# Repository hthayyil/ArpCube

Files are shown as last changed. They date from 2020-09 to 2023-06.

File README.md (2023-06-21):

# ArpCube
**Arduino Code and schematics for the ArpCube Midi Controller created by Sister Engineering**

The ArpCube is an Arduino powered MIDI controller. The cube can be plugged into a computer to process the button controls into MIDI, 
or it can be plugged into any device that understands MIDI. 
The ArpCube can act as a standalone MIDI trigger or it can be used as an arpeggiator. 
When in arpeggiator mode, the ArpCube allows a user to step through a selected sequence of notes based on the input buttons. 

Powered by USB C. MIDI signals are sent using a DIN socket. 
## Modes

**MIDI Mode**
When in MIDI mode, pressing a button will send it’s corresponding MIDI On signal out once, and releasing a button will send a MIDI Off signal. 
Pressing and holding a button will sustain the note until the button is released. 
When in MIDI Mode the user can use the KEY potentiometer to choose which key the notes are mapped to. 
The chosen key will be displayed on the LCD screen.
The user can also use the OCTAVE potentiometer to transpose the notes on each key up or down octaves.

**Mono Arp Mode** 
In Mono mode the cube steps through a sequence of 32 steps. 
Each step is represented by a button, and when a step is reached the button light will turn on. 
When the arpeggiator reaches a step and the user presses any of the 32 buttons, that step will save the note that was just pressed and replay that note when it reaches that step. 
Every step can only support one note, so if a step already has a note saved and the user presses another note, the previously programmed note will be erased and the new note will be saved. 
The user can transpose octave and keys using the OCTAVE and KEY Potentiometer, and the user can also control the BPM using the BPM Potentiometer.
The BPM, and key will be displayed on the LCD screen.

**Poly Arp Mode** 
In Poly Mode the cube steps through a sequence of 8 steps. 
Each step is represented by a column on the button matrix. Each step can hold up to 4 notes. 
When the sequence is on a step and a user presses a key that note will be added to that step. 
When the step has reached 4 notes stored, and the user adds another note, all old notes will be cleared and the new note will be stored. 
The user can transpose octave and keys using the OCTAVE and KEY pot, and control BPM using the BPM pot.
The BPM, and key will be displayed on the LCD screen.

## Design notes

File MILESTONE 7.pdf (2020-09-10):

# ArpCube

An Arduino MIDI controller by: Hanna Thayyil
Hthayyi2
Hthayyi2@uic.edu
Wisam Abunimeh
Wabuni2
Wabuni2@uic.edu

Abstract:

The ArpCube is an Arduino powered MIDI controller. The cube can be plugged into a computer to process the button controls into MIDI, or it can be plugged into a device that understands MIDI such as a synthesizer. The ArpCube can act as a standalone MID trigger or it can be used as an arpeggiator. An arpeggio is a musical term for playing the notes of a chord in succession. When in arpeggiator mode, the ArpCube allows a user to step through a selected sequence of notes based on the input buttons. The ArpCube does not support MIDI-IN or MIDI-THRU signals, only MIDI-OUT.
Description & How to Use:
The ArpCube is inspired by the Novation Launchpad, and the Monome MIDI controller. It can be used with any music software or it can be used with other hardware synthesizers that understand MIDI. The ArpCube is not a standalone instrument, it does not create any audio, it must be used in tandem with a Midi receiving instrument or computer digital audio workspace.
The ArpCube features 32 back-lit buttons used as inputs and outputs. Each button sends a MIDI signal that represents a note. The cube has 3 different modes -MIDI mode- When in MIDI mode pressing a button will send it’s corresponding MIDI On signal out once, and releasing a button will send a MIDI Off signal. Pressing and holding a button will sustain the note until the button is released. When in MIDI Mode the user can use the KEY potentiometer to choose which key the notes are mapped to. The user can also use the OCTAVE potentiometer to transpose the notes on each key up or down octaves.

-Mono Arp Mode- In Mono mode the cube steps through a sequence of 32 steps. Each step is represented by the button, and when a step is reached the button light will turn on. When the arpeggiator reaches a step and the user presses any of the 32 buttons, that step will save the note that was just pressed and play that note when it reaches that step. Every step can only support one note, so if a step already has a note saved and the user presses another note, the old note will be erased and the new note will be saved. The user can transpose octave and keys using the OCTAVE and KEY Potentiometer, and the user can also control the BPM using the BPM Potentiometer.
-Poly Arp Mode- In Poly Mode the cube steps through a sequence of 8 steps. Each step is represented by a column on the button matrix. Each step can hold up to 4 notes. When the sequence is on a step and a user presses a key that note will be added to that step. When the step has reached 4 notes stored, and the user adds another note, all old notes will be cleared and the new note will be stored. The user can transpose octave and keys using the OCTAVE and KEY pot, and control BPM using the BPM pot.
The ArpCube was designed to make use of two Arduino’s based on the sheer amount of inputs used. They will be connected using Bluetooth bus. One Arduino will receive information from the various inputs and another will be used to send outputs to both the ArpCube and other connected devices. The ArpCube will use a DIN socket to send MIDI messages to a MIDI understanding device.
INPUT/OUTPUT
Inputs for the device will be 32 buttons, three potentiometers and two switches. The potentiometers allow transposing key, octave and changing BPM. The two switches let you toggle between the three modes. Output will be 32 3mm LED’s used as indicators that a button is switched on or off- these LED’s back light the buttons. We will be using Adafruit’s Trellis keypad driver for simplicity. An LCD screen is used as output to display which mode the user is in, as well as which key they are in and what their current BPM is.

## Original Work

The ArpCube is unique because it acts as both a standalone MIDI controller and an arpeggiator. Many documented projects only feature a controller, but the arpeggiator algorithms are completely original. Many DIY projects also only feature 16 or 8 buttons. Since there are 7 notes or 12 semitones in a western scale, we wanted to make the number of buttons on the ArpCube be able to support at least 2 octaves. The Arpcube however supports every possible MIDI octave. We have also not encountered MIDI controller that allows the user to traverse through different Keys, since it is not immediately clear which button is programmed to which note, we wanted to make the MIDI controller easily intuitive and musical. We wrote two original libraries, for Arpeggiating and Note Mapping.
Materials:
2x Arduino Uno
2x Silicone Elastomer Key Pads - https://www.adafruit.com/product/1611 2x Adafruit Trellis PCB Drivers https://www.adafruit.com/product/1616 32x While 3mm LED
1x LCD screen
2x resistors (220 Ohm)
3x Rotary potentiometer (50K) 1x Capacitor (0.05 mF)
2x Toggle Switch
1x DIN socket
References

Sending and Receiving MIDI (we will be using MIDI Send not receive) https://www.instructables.com/id/Send-and-Receive-MIDI-with-Arduino/

Serial to MIDI References
https://projectgus.github.io/hairless-midiserial/

Arduino sequencer used as reference https://learn.sparkfun.com/tutorials/build-an-auduino-step-sequencer/all

Libraries Used: Software Serial, Arduino STL, LiquidCrystal, Wire.h, Adafruit Trellis, MIDIUSB, MIDI.h

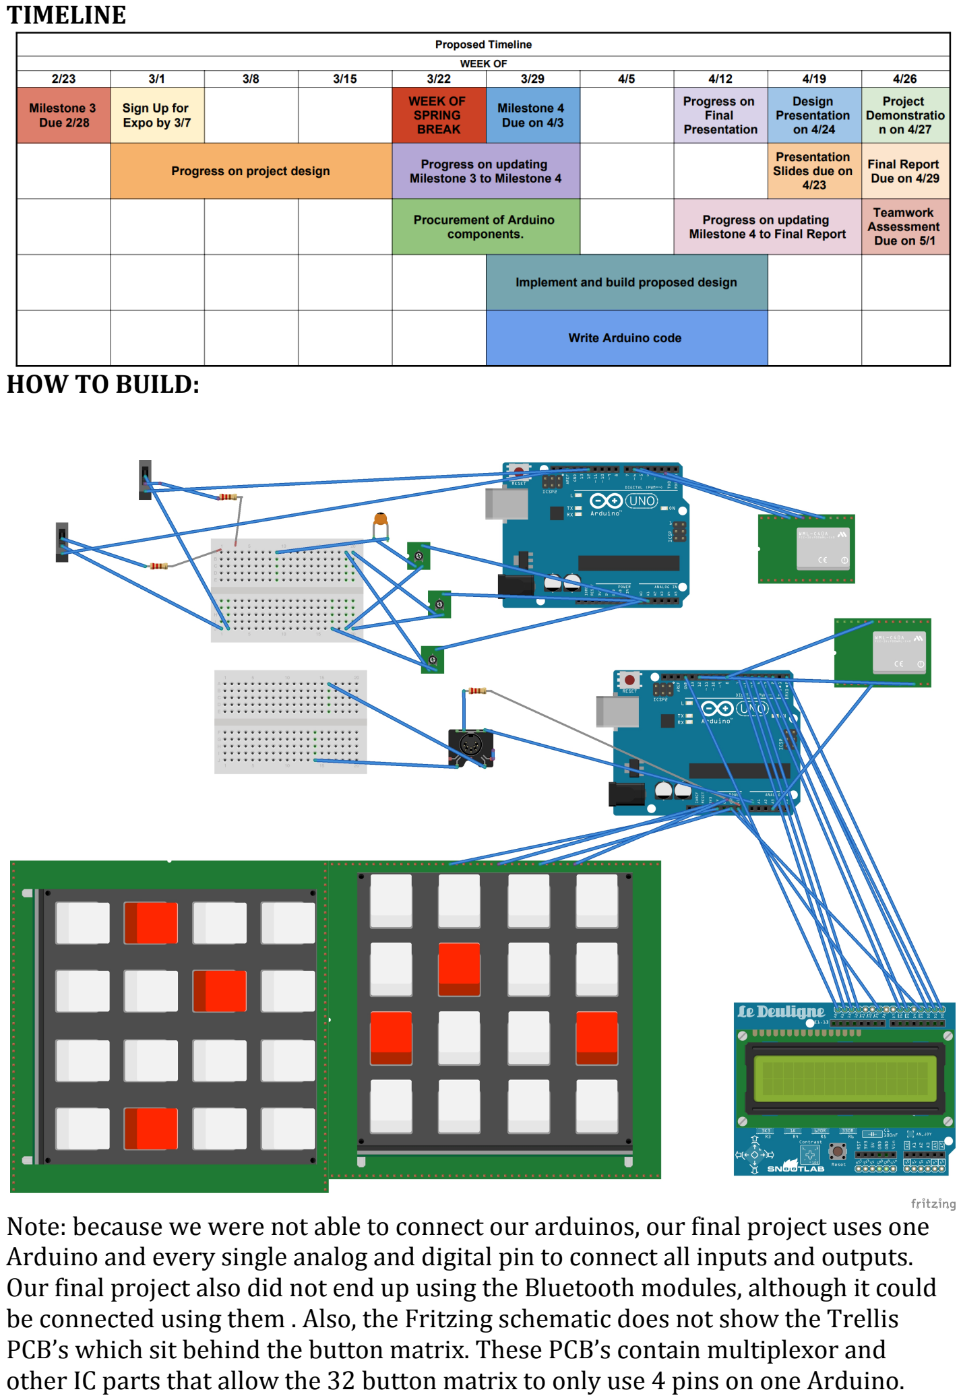
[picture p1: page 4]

TIMELINE

HOW TO BUILD:

Note: because we were not able to connect our arduinos, our final project uses one Arduino and every single analog and digital pin to connect all inputs and outputs. Our final project also did not end up using the Bluetooth modules, although it could be connected using them . Also, the Fritzing schematic does not show the Trellis PCB’s which sit behind the button matrix. These PCB’s contain multiplexor and other IC parts that allow the 32 button matrix to only use 4 pins on one Arduino.

Connect Trellis Vin to 5V and Ground to ground. Connect the INT wire to pin #A2
Connect I2C SDA pin to your Arduino SDA line PIN A4 Connect I2C SCL pin to your Arduino SCL line PIN A5 All Trellises share the SDA, SCL and INT pin.
OCTAVE POT - potPin is on analog pin 0
TEMPO POT is on analog pin 1
SWITCH1 is on digital Pin 6
SWITCH 2 is on digital Pin 7
KEY POT is on pin A2

LCD set up: LiquidCrystal lcd(13, 12, 8, 9, 10, 11);

-Commented in the code sketch are the above instructions on which inputs must be connected to which pins.

Challenges:
Debouncing potentiometers during the arpeggiator was a challenge which was solved using a 0.05 mF capacitor.
Testing the DIN socket with devices other then a digital audio workstation was a challenge because of quarantine restrictions. Currently, if the user connects a MIDI out cable to USB to the computer, it works perfectly fine, but this was not tested connecting to any other device.

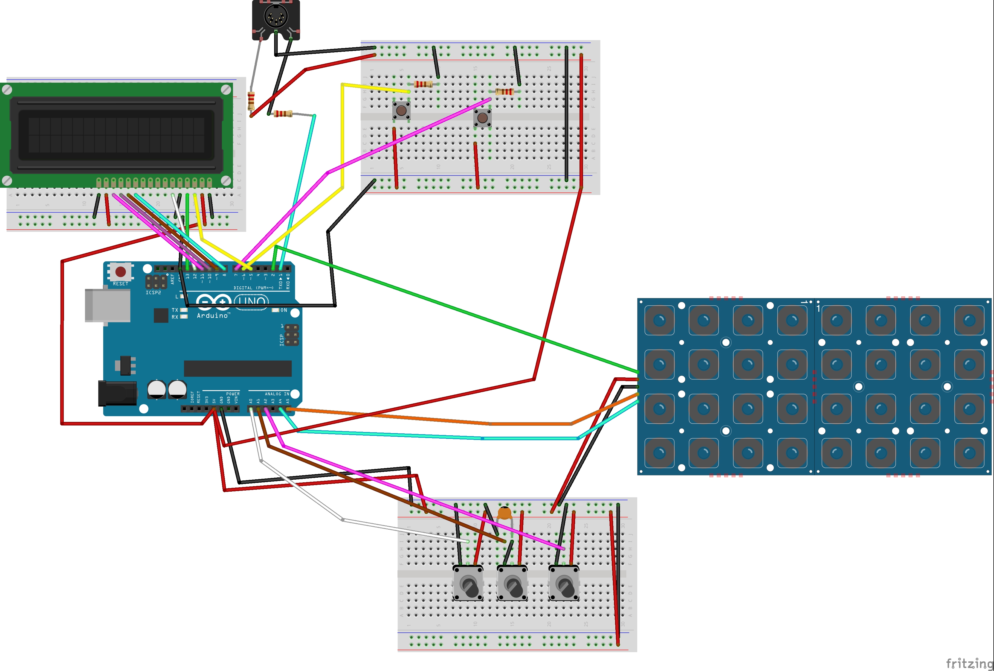
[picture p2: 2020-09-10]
arpcube-final.jpg

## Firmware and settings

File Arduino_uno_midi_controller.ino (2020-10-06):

/*Arduino Code for the ARP CUBE 
 * written by Hanna Thayyil 
 * https://github.com/hthayyil/ArpCube
*/

#include <SoftwareSerial.h>
#include <MIDImap.h>
#include <ArduinoSTL.h>
#include <LiquidCrystal.h> 
#include <Wire.h>
#include "Adafruit_Trellis.h"
#include <MIDI.h>
#include <ARPbeta.h>




//DEFINE MODES:
#define MIDICONTROLLER 0
#define ARPCUBE 1
#define POLY 2
#define FUNCTION 3


// Define MODE: MIDICONTROLLER MODE is set as default
int MODE = MIDICONTROLLER; 

//Call upon Trellis libary for button pad commands
Adafruit_Trellis matrix0 = Adafruit_Trellis();
Adafruit_Trellis matrix1 = Adafruit_Trellis();

//Inititalize TRELLIS
Adafruit_TrellisSet trellis =  Adafruit_TrellisSet(&matrix0, &matrix1);

//set the interrupt pin to A2
#define INTPIN 2
//set the number of trellis boards and number of keys we are using
#define NUMTRELLIS 2
#define numKeys (NUMTRELLIS * 16)

/*
 Connect Trellis Vin to 5V and Ground to ground.
 Connect the INT wire to pin #A2
 Connect I2C SDA pin to your Arduino SDA line PIN A4
 Connect I2C SCL pin to your Arduino SCL line PIN A5
 All Trellises share the SDA, SCL and INT pin
 OCTAVE POT - potPin is on analog pin 0
 TEMPO POT is on analog pin 1
 SWITCH is on digital Pin 6
 SWITCH 2 is on digital pin7
 KEY POT is on pin A2
*/

//DIN 2 to GROUND
//DIN 4 to 220 OHM resistor to D1
//DIN 5 to 5V
 

//SET MIDI COMMANDS
int velocity = 100;//velocity of MIDI notes, must be between 0 and 127
 //higher velocity usually makes MIDI instruments louder
int noteON = 144;//144 = 10010000 in binary, note on command
int noteOFF = 128;//128 = 10000000 in binary, note off command

//OCTAVE POT is on analog pin 0
int potPin = 0; //potentiometer is on A0
long potVal; //value to store potentiometer reading
long prevPotVal = 0;

//TEMPO POT is on analog pin 1
int tempoPin = 1;
long tempo; //value to store potentiometer reading
long prevTempo = 0;
long BPM;

//SWITCH is on digital pin 6
int switchPin = 6;

//BUTTON is on pin 7
int button = 7;
//unsigned long lastDebounceTime = 0;  // the last time the output pin was toggled
//unsigned long debounceDelay = 50;    // the debounce time; increase if the output flickers
//int prevButtonState = LOW;

//function button is on pin 3
int funcButton = 3;
int led = 4; 

//POTENTIOMETER to indicate key is on pin A2
int keyPot = 2;
long keyVal;

volatile int arpSeq[32];
//bool wasPressed = false;
//volatile int polySeq[8][4];

//used for poly mode
int noteOrderPoly[8][4] = 
{ {28, 29, 30, 31},
  {24, 25, 26, 27},
  {20, 21, 22, 23},
  {16, 17, 18, 19},
  {12, 13, 14, 15},
  {8,   9, 10, 11},
  {4,   5,  6,  7},
  {0,   1,  2,  3} };

//Maps trellis matrix button order
int noteOrder[32] = {
  28, 24, 20, 16, 12 ,8, 4 ,0, 
  29, 25, 21, 17, 13, 9, 5,1,
  30, 26, 22, 18, 14, 10, 6, 2,
  31, 27, 23, 19, 15, 11, 7, 3
};


int numSteps = 31;

//Class objects- defined in the MIDImap and ARP libraries
MIDImap mp;
ARP arp;

//Set Contrast: used to surpass need for POT on LCD
int Contrast=100;
LiquidCrystal lcd(13, 12, 8, 9, 10, 11);  

//INITIALIZE SOFTWARE SERIAL: to use DIN Socket
const byte rxPin = 0; // not used for the moment
const byte txPin = 1;
SoftwareSerial mySerial(rxPin, txPin);
boolean changed = false;

//ClearSequence: Resets the ARP sequence
void clearSequence(){
   for(int i=0; i<32; i++){
      arpSeq[i] = -1;
   }
   numSteps = 31;
}

//function to clear all LEDS
void clearLEDS(){
      for (uint8_t i=0; i<numKeys; i++) {
           // MIDImessage(noteOFF, mp.noteCalc(i, analogRead(potPin),analogRead(keyPot)), velocity);//turn note off 
            trellis.clrLED(i);
        }     
      trellis.writeDisplay();    
}

//function to clear all notes turn everything off
void clearNotes(){
 for (uint8_t i=0; i<127; i++) {
   MIDImessage(noteOFF, i, velocity);//turn note off 
}
  
}

  //send MIDI message through USB port
void MIDImessage(int command, int MIDInote, int MIDIvelocity) {
  Serial.write(command);//send note on or note off command 
  Serial.write(MIDInote);//send pitch data
  Serial.write(MIDIvelocity);//send velocity data
}

void setup() {
   // Set MIDI baud rate:
   //9600 to interface with Hairless midi software 
   pinMode(button, INPUT);
   
   pinMode( txPin, OUTPUT);
   pinMode(funcButton, INPUT);
   pinMode(led, OUTPUT);
   
   //initialize contrast for LCD
   analogWrite(5,Contrast);
   
   lcd.begin(16, 2);
   lcd.print("ARPCUBE");
   
   Serial.begin(31250);
 // Serial.begin(9600);
   clearSequence();
  // INT pin requires a pullup
  pinMode(INTPIN, INPUT);

  pinMode(switchPin, INPUT);
 keyVal = analogRead(keyPot);

//set default tempo to 120 BPM 60k/120
 tempo = 500; 
 
  
 // attachInterrupt(digitalPinToInterrupt(INTPIN), addButton, FALLING);
  
  // begin() with the addresses of each panel in order
  trellis.begin(0x71, 0x70);  // only one

  // light up all the LEDs in order
  for (uint8_t i=0; i<numKeys; i++) {
    trellis.setLED(i);
    trellis.writeDisplay();
    if (i == 2 || i == 4 || i == 5 || i == 7) {
      delay(100);//hold note for 300ms
     } else if (i == 8) {
        delay(100);//hold note for 300ms
      } else if (i == 13 || i == 15) {      
        delay(100);//hold note for 300ms
      }
  }
  
  // then turn them all off
  for (uint8_t i=0; i<numKeys; i++) {
    trellis.clrLED(i);
    trellis.writeDisplay();    
    delay(30);
  }
}//end setup


void loop() {

  //read the value of the pin to determine which mode to be in
  if (digitalRead(switchPin) == HIGH) {
    MODE = MIDICONTROLLER;
    arp.clear();
    clearSequence();
    lcd.setCursor(0,0);
    lcd.print("MIDI MODE          ");
    lcd.setCursor(0, 1); 
    keyVal = analogRead(keyPot);
    lcd.print(mp.printKey(keyVal).c_str());
  }
 
  
   else { 
     clearNotes();
      MODE = ARPCUBE;
      lcd.setCursor(0,0);
      lcd.print("MONO BPM: ");
      lcd.print(BPM);
      lcd.setCursor(0, 1); 
      keyVal = analogRead(keyPot);
      lcd.print(mp.printKey(keyVal).c_str());
   }
  
  delay(30); // 30ms delay helps for latency
  
  //octave pot
   potVal = analogRead(potPin);


  if (keyVal!= analogRead(keyPot)){
     
     lcd.setCursor(0, 1); 
     keyVal = analogRead(keyPot);
     lcd.print(mp.printKey(keyVal).c_str());
  }


 
  //MIDICONTROLLER MODE
 if  (MODE == MIDICONTROLLER) {
    
    // If a button was just pressed or released
    if (trellis.readSwitches()) {
      // go through every button and check new status
      
      for (uint8_t i=0; i<numKeys; i++) {
        if (trellis.justPressed(i)) {
          
            MIDImessage(noteON, mp.noteCalc(i, potVal, keyVal), velocity);//turn note on
            trellis.setLED(i);
        } 
         // if it was released, turn it off
         if (trellis.justReleased(i)) {
            MIDImessage(noteOFF, mp.noteCalc(i, potVal, keyVal), velocity);//turn note off 
            trellis.clrLED(i);
        }
      }
      
      // tell the trellis to set the LEDs we requested
      trellis.writeDisplay();
    }
   
  
  } //end midicontroller mode


//ARP MODE

while (MODE ==ARPCUBE) {
      lcd.setCursor(0,0);
      lcd.print("MONO BPM: ");
      lcd.print(BPM);
      lcd.setCursor(0, 1); 
      keyVal = analogRead(keyPot);
      lcd.print(mp.printKey(keyVal).c_str());
  
  for (uint8_t k=0; k<=numSteps; k++) {
  
  //read Mode switch 
    if (digitalRead(switchPin) == HIGH) {
      MODE = MIDICONTROLLER;
       break;
    }
    
  if (digitalRead(button) == HIGH) {
     lcd.clear();
     MODE = POLY;
     break;   
  }
  
  if (digitalRead(funcButton) == HIGH) {
      digitalWrite(led, HIGH);
      lcd.clear();
      MODE = FUNCTION;
      changed = false;
     break;
  }

  
   //reading the TEMPO POT
    if(prevTempo != analogRead(tempoPin)){
     prevTempo = analogRead(tempoPin);
     BPM = map(prevTempo, 0, 1023, 80, 800);
     //tempo indiciates BPM in ms
     tempo = 60000/BPM;
     lcd.setCursor(0,0);
     lcd.print("MONO BPM: ");
     lcd.print(BPM);
     lcd.print("    ");    
  }

  //reading the KEY POT
   if (keyVal!= analogRead(keyPot)){
    //lcd.clear();
     lcd.setCursor(0, 1); 
     keyVal = analogRead(keyPot);
    lcd.print(mp.printKey(keyVal).c_str());
  }
  potVal = analogRead(potPin);
  
   if (trellis.readSwitches()) {
    for (uint8_t i=0; i<numKeys; i++) {
      int temp[4];
        if (trellis.justPressed(i)) {
            trellis.setLED(i);
             arpSeq[k] = i;
             MIDImessage(noteON, mp.noteCalc(i, potVal,keyVal), velocity);//turn note on        
        } 
         // if it was released, turn it off
         else if (trellis.justReleased(i)) {
            MIDImessage(noteOFF, mp.noteCalc(i, potVal, keyVal), velocity);//turn note off 
            trellis.clrLED(i);
        }
         
      }
      trellis.writeDisplay();
   }//end if readswitches
      // tell the trellis to set the LEDs we requested
      trellis.setLED(noteOrder[k]);
      trellis.writeDisplay();
      
      if (arpSeq[k] != -1)  MIDImessage(noteON, mp.noteCalc(arpSeq[k], potVal,keyVal), velocity);//turn note on     
           delay(tempo);
     
      if (arpSeq[k] != -1)  MIDImessage(noteOFF, mp.noteCalc(arpSeq[k], potVal,keyVal), velocity);//turn note off
      
    trellis.clrLED(noteOrder[k]);
    trellis.writeDisplay(); 
      
    }//cycle thru arp

  
}//end while ARP

 while (MODE == POLY) {
    lcd.setCursor(0,0);
     lcd.print("POLY BPM: ");
     lcd.print(BPM);
     lcd.print("    ");    
    lcd.setCursor(0, 1); 
    keyVal = analogRead(keyPot);
    lcd.print(mp.printKey(keyVal).c_str());

  for (int i = 0 ; i < 8; i++){

     //read Mode switch 
    if (digitalRead(button) == LOW) {
    
       MODE = ARPCUBE;
       break;
      }
    //read Mode switch 
    if (digitalRead(switchPin) == HIGH) {
        MODE = MIDICONTROLLER;
       break;
     }

         //reading the KEY POT
    if (keyVal!= analogRead(keyPot)){
    //lcd.clear();
     lcd.setCursor(0, 1); 
     keyVal = analogRead(keyPot);
     lcd.print(mp.printKey(keyVal).c_str());
   }
     //reading the TEMPO POT
    if(prevTempo != analogRead(tempoPin)){
     prevTempo = analogRead(tempoPin);
     BPM = map(prevTempo, 0, 1023, 40, 800);
     //tempo indiciates BPM in ms
     tempo = 60000/BPM;
     lcd.setCursor(0,0);
     lcd.print("POLY BPM: ");
     lcd.print(BPM);
     lcd.print("    ");    
  }

   
   potVal = analogRead(potPin);
  

     if (trellis.readSwitches()) {
        for (uint8_t q=0; q<numKeys; q++) {
        if (trellis.justPressed(q)) {
            trellis.setLED(q);
            arp.addToVec(i, q);
             MIDImessage(noteON, mp.noteCalc(q, potVal,keyVal), velocity);//turn note on        
         } 
         // if it was released, turn it off
         else if (trellis.justReleased(q)) {
            MIDImessage(noteOFF, mp.noteCalc(q, potVal, keyVal), velocity);//turn note off 
            trellis.clrLED(q);
         }
         
      }
      trellis.writeDisplay();
   }//end if readswitches

  
    
    for (int p = 0; p <4; p ++){
         trellis.setLED(noteOrderPoly[i][p]);
     }

      //PLAY THE NOTES Se
      for (int j = 0; j < 4; j ++) {
   
            int but1 = arp.findNote(i, j);
            if (but1 != -1) MIDImessage(noteON, mp.noteCalc(but1, potVal, keyVal), velocity);
      }
    
     trellis.writeDisplay();
      delay(tempo);
     
      //if (arpSeq[k] != -1)  MIDImessage(noteOFF, mp.noteCalc(arpSeq[k], potVal,keyVal), velocity);//turn note on  

    for (int j = 0; j < 4; j ++) {

         int but2 = arp.findNote(i, j);
         if (but2 != -1)  MIDImessage(noteOFF, mp.noteCalc(but2, potVal, keyVal), velocity);//turn note off          
       }
      
    for (int p = 0; p <4; p ++){
         trellis.clrLED(noteOrderPoly[i][p]);
     }
     trellis.writeDisplay(); 

    
   }//end for 0 - 8

   
  
 }//end if MODE = POLY
 
 int curStep = 0;
 int tempNumSteps = 31;


 //FUNCTION MODE
 while (MODE == FUNCTION){
 delay(300);
   lcd.setCursor(0,0);
   lcd.print("FUNCTION     ");
   //reading the KEY POT
   if (changed == true) {
        digitalWrite(led, LOW);
        changed = false;
        MODE = ARPCUBE;
        clearLEDS();
        break;
   }

while(1) {
  delay(90);
  if( digitalRead(funcButton) == HIGH || changed == true) {
    changed = true;
    break;
  }

  //if the key pot changes
      if ((keyVal > analogRead(keyPot) + 10) || (keyVal < analogRead(keyPot) - 10 )){
       
           keyVal = analogRead(keyPot);
           tempNumSteps = map(keyVal, 0, 1023, 0, 31);
           lcd.setCursor(0, 1); 
           lcd.print("Seq Length: ");
           lcd.print(tempNumSteps + 1);
           lcd.print("     ");    
       


         for (uint8_t q=0; q<32; q++) {
  
          if (q <= tempNumSteps) trellis.setLED(noteOrder[q]);
          else trellis.clrLED(noteOrder[q]);
        }
          trellis.writeDisplay();
      }//end if key pot changes

      //if the tempo pin changes
       if( (prevTempo > analogRead(tempoPin) + 10) || (prevTempo < analogRead(tempoPin) - 20) ) {
      
          prevTempo = analogRead(tempoPin);
          curStep = map(prevTempo, 0, 1023, 0, 31);
       
         //turn off all LED's except the current step 
          for (uint8_t q=0; q<32; q++) {
          if (q == curStep)  { 
            trellis.setLED(noteOrder[curStep]);
            }
            else trellis.clrLED(noteOrder[q]);
           }
             trellis.writeDisplay();
   
    
             
        }//end if tempo pin changes
       

      if (trellis.readSwitches()) {
      // go through every button and check new status
 
      for (uint8_t i=0; i<numKeys; i++) {
        if (trellis.justPressed(i)) {
            arpSeq[curStep] = i;
            MIDImessage(noteON, mp.noteCalc(i, analogRead(potPin), analogRead(keyPot)), velocity);//turn note on
            trellis.setLED(i);
            //if a key is pressed and they are also pressing the function 
        
        } 
         // if it was released, turn it off
         else if (trellis.justReleased(i)) {
            MIDImessage(noteOFF, mp.noteCalc(i, analogRead(potPin),analogRead(keyPot)), velocity);//turn note off 
            trellis.clrLED(i);
        }
      }
      // tell the trellis to set the LEDs we requested
      trellis.writeDisplay();
   
    }//end if read switches



}//end while 1
numSteps = tempNumSteps;

  
 } //end while mode == function
  
}//end loop 
